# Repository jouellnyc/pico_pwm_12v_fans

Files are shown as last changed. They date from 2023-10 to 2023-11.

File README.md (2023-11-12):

# L9110 
There appear to be few guides on the internet that walk someone through setting up a Raspberry Pi Pico and using an L9110 module with a 12V DC fan/motor and [pwm](https://docs.micropython.org/en/latest/library/machine.PWM.html).

There are some that come close, but add additional components and some that have mostly text, however here is a simple example of how to use just those components in a very simple fashion.
There are caveats/warning about using 12V with 3.3/5V microcontrollers in some forums, but you can follow this setup safely - make sure the current does not exceed the rating of the L9110. 

For *smaller* hobby motors this is typically not a problem, but beware of their polarities and if they only move forward in one direction. The stall current at full 12V power, may exceed the limit of L9110. If you were to try it at full blast it will destroy the L9110(smoke/etc). This is %100 true of the larger fan in this repo.

Lots of documentation/urls exist inside the pwm_runner file as well.

NOTE: I connected the pi to "MotorB" because it was simply easier/closer to me at the time.

## Components
- [L9110](https://www.amazon.com/HiLetgo-H-bridge-Stepper-Controller-Arduino/dp/B00M0F243E)
- Pi Pico
- [Small 12 V Fan](https://www.aliexpress.us/item/3256802262312152.html)
- [Larger 12 V Fan](https://www.amazon.com/gp/product/B0BXDGWS4J/)
- [Power Jack Adapter](https://www.amazon.com/gp/product/B07C61434H/)

## Fritzing Schematic
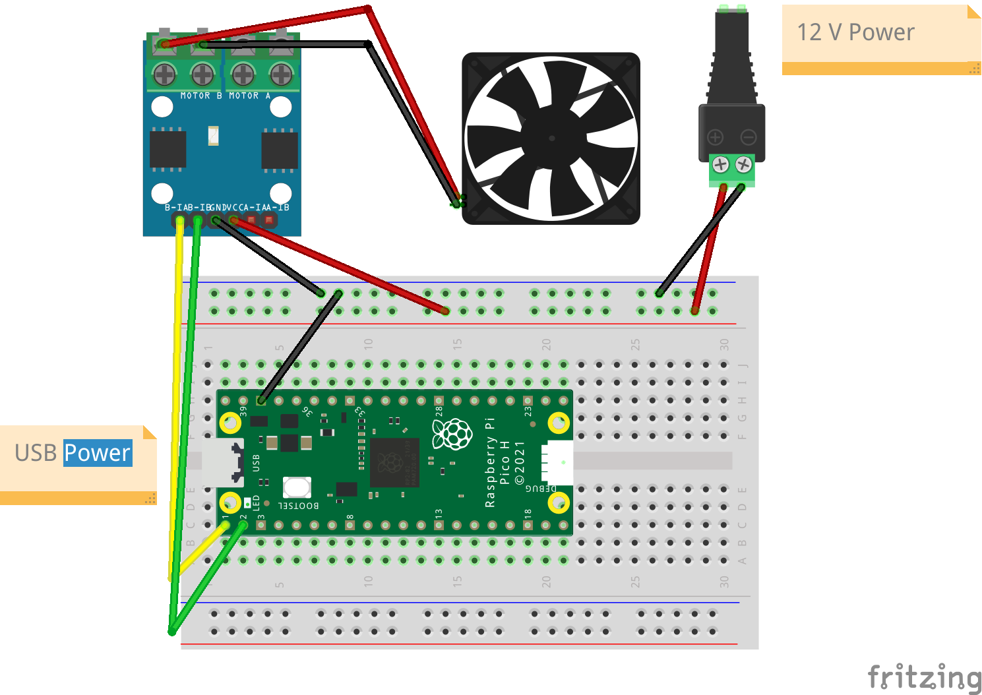
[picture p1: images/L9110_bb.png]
BreadBoard


## Connections
| Pico | L9110| 
| --- | --- |
| GPIO 0 | Motor B1A |
| GPIO 1 | Motor B1B |

| Pico | Breadboard|
| --- | --- |
| GND | GND/rail  |

| Breadboard | L9110|
| --- | --- |
| GND/rail | GND |
| +/5V/rail | VCC |

| Breadboard | 5V Power (Terminal Block)|
| --- | --- |
| GND | -/5V |
| PWR | +/5V |

## ```pwm_runner```
This will run a for loop using PWM at high and slow speeds.  

So yes, you can control a 2-pin DC fan with Pico Pi and PWM.

## Comments on squeeling sound at low pwm frequency. 

Best to play around for what suits your fan.  See these links:

[Forum](https://picaxeforum.co.uk/threads/is-a-small-high-pitched-noise-normal-when-using-pwmout.9077/)

[Reddit](https://www.reddit.com/r/Motors/comments/ojn64m/12v_pwm_fan_makes_high_pitch_noise_when_hooked_up/)

# L298N:
There are so many writes up on the [L298N](https://www.amazon.com/gp/product/B0C5JCF5RS), here's 2:

[MCLAB](https://microcontrollerslab.com/dc-motor-l298n-driver-raspberry-pi-pico-tutorial/)
[HACK.IO](https://www.hackster.io/Ramji_Patel/raspberry-pi-pico-and-l298n-motor-driver-62bfa0)

Remember: 
- Remove the 'ENA' jumper and put GPIO4/Phys Pin 6 attached to it.
- This is valid for full speed:

```
IN1.low(); IN2.high() 
speed = PWM(Pin(4), freq=450, duty_u16=65535)
```
if you are setting up like this:
```
IN1 = Pin(3, Pin.OUT)
IN2 = Pin(2, Pin.OUT)
```

- Recall the 12V Fans do NOT move 'backwards'

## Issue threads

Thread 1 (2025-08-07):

PWM frequency

unaszplodr, 2025-08-07:
Thanks for sharing all this. It seems that a PWM frequency 25kHz (i.e. 250000) is best for most 12v axial fans, though apparently some are happy at 15kHz or even less. The values in your code are way too low, result in oscillation and/or whining from the Gdstime fans I'm working with. As soon as I looked up the appropriate values and punched 250000 in, the fans began to play nice. The L9110s does seem to struggle, though. With two fans, one per channel, 360mA  in total, the driver is running one fan faster than the other.

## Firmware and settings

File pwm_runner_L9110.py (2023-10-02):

"""

l9110

Need latest mp for params and pwm:
https://github.com/orgs/micropython/discussions/12162

DS - https://www.makerfabs.com/desfile/files/datasheet-l9110.pdf

Best picture - https://www.makerfabs.com/l9110-dual-channel-h-bridge-motor-driver-module-12v-800ma.html

Careful with 12 V - https://forums.raspberrypi.com/viewtopic.php?t=292239
                  - https://www.electroschematics.com/l9110-motor-driver-primer

How to set it up and use it - https://forum.micropython.org/viewtopic.php?t=5736

Other logical reference https://www.bananarobotics.com/shop/How-to-use-the-HG7881-(L9110)-Dual-Channel-Motor-Driver-Module

"""


from machine import Pin, PWM
import time

B1A = Pin(0, Pin.OUT)
B1B = Pin(1, Pin.OUT)

""" 3-5V DC Hobby Fan 
The normal full power operation of the DC hobby fan is clockwise  
when holding the fan with the black wire on the left

#Forward
B1A.value(0); B1B.value(1) 
#Stop
B1A.value(1); B1B.value(1) 
#Backward
B1A.value(1); B1B.value(0)
#Stop
B1A.value(0); B1B.value(0)  
"""


""" small 12V DC Fan
- https://www.aliexpress.us/item/3256802262312152.html
- 12v - 4010

#Forward
B1A.value(0); B1B.value(1)

- All other combos do not make any difference as it appears to only move in one direction.

- Therefore, by default B1B must be used as the speed with PWM:

#Stopped
pwm_speed = PWM(B1B, freq=1000, duty_u16=0)

#Full on 
pwm_speed = PWM(B1B, freq=1000, duty_u16=65535)

With full 12V DC on the L9110, the pi/pico/everything is stable.

#450 is a lot less noisy than 1000 at low frequency!
pwm_speed = PWM(B1B, freq=450, duty_u16=0)
"""

""" larger 12V DC Fan
- https://www.amazon.com/gp/product/B0BXDGWS4J/
CHUIZIRIG 120x120x25mm 120mm 12V 0.45A 2Pin Computer Fan with AC Plug Cabinet Fan DC Brushless Cooling
- Fan Brushless DC Cooler Case Cooling Fan 12V gpu Mining rig Fan(1 * 3000RPM Fan)

#Forward
B1A.value(0); B1B.value(1)
- All other combos do not make any difference as it appears to only move in one direction.
- I.E, if you try for   B1A.value(1); B1B.value(0) and put in on 12V, you are guaranteed to fry the L9110!
  The  stall current will be too much.
  
#3500 is a lot less noisy than 1000 at low frequency!
pwm_speed = PWM(B1B, freq=3500, duty_u16=0)
"""

"""
NO PWM UP TO  THIS POINT !!! 

Software: I use 1 pin as direction pin and the other pin as speed pin.
If the direction is low then the motor will get power when ever the speed pin is high
so the speed the motor will spin at will be the duty with of the speed pin i.e PWM_duty = desired_speed.

If the direction is high then motor will spin the other way and the motor will get power anytime the speed pin is
low so you have to invert the PWM duty i.e PWM_duty = 100 - desired_speed
"""

""" Typically safe defaults as per above """
#Left most connection on the L9110
B1A.value(0)
#Immediate to the right of B1A
B1B.value(1); 
pwm_speed = PWM(B1B, freq=1000, duty_u16=0)

"""
#Stop 
pwm_speed.duty_u16(0)
pwm.deinit()
#Full on 
pwm_speed.duty_u16(65535)
"""

while True:
    
    for x in range(25000,65535,1000):
        print(f"== {x} ==")
        pwm_speed.duty_u16(x)
        time.sleep(1)
        
    for x in range(65535,25000,-1000):
        print(f"== {x} ==")
        pwm_speed.duty_u16(x)
        time.sleep(1)
    
        

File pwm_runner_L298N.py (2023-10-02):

"""
Notes for the L298N:

https://microcontrollerslab.com/dc-motor-l298n-driver-raspberry-pi-pico-tutorial/
https://www.hackster.io/Ramji_Patel/raspberry-pi-pico-and-l298n-motor-driver-62bfa0

Remove the ENA jumper and put GPIO4/Phys Pin 6 attached to it.

Keeping in mind this is valid:

IN1.low(); IN2.high() 
speed = PWM(Pin(4), freq=450, duty_u16=65535)

For full speed using:
IN1 = Pin(3, Pin.OUT)
IN2 = Pin(2, Pin.OUT)

Recall the 12 V fans do NOT move 'backwards'

"""


from machine import Pin, PWM
from time import sleep

IN1 = Pin(3, Pin.OUT)
IN2 = Pin(2, Pin.OUT)

IN1.low(); IN2.high() 
speed = PWM(Pin(4), freq=450, duty_u16=0)

print("Starting Now")
      
while True:
        

        print("4")
        speed.duty_u16(40000)
        sleep(5)
        
        print("5")
        speed.duty_u16(50000)
        sleep(5)
        
        print("6")
        speed.duty_u16(65535)
        sleep(5)
        

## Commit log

2023-10-02 Comments on 12 V
2025-05-12 Add Button PWN Script (with reversed logic)
    [rev_button_stay.py]
